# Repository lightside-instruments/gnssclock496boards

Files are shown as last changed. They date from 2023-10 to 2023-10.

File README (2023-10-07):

The gnssclock496boards is an open hardware extension module for Ultra96
or other 96boards CE compatible devices. It uses the u-blox LEA-M8T
module or other LEA-* compatible modules.

In addition to a 1 sec PPS signal which is available on almost all
GNSS boards it has high frequency (e.g. 10 MHz clock signal) that
can be used for better precision timestamp or frequency synchronization.

Published by Lightside Instruments AS.

The initial release gnssclock496boards-1.0 includes schematic and PCB
design files for KiCAD.

The project is published by Lightside Instruments AS
under TAPR Open Hardware License. Read the LICENSE file
for details.

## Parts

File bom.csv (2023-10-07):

Reference | Quantity | Identifier | footprint | Value | Tolerance | Voltage | Current | Power | PN
BT1 | 1 |  | ice4pi:BatteryHolder_Keystone_2450 | Battery_Cell |  |  |  |  | SMTU2450N-LF.TR
C1;C5 | 2 |  | Resistor_SMD:R_0402_1005Metric | 1uF |  |  |  |  | 885012105012
C2;C7 | 2 |  | Capacitor_SMD:C_0402_1005Metric | 10uF |  |  |  |  | ZRB15XR61A106ME01D
C3 | 1 |  | Capacitor_SMD:C_0402_1005Metric | 1uF |  |  |  |  | 885012105012
C4 | 1 |  | Inductor_SMD:L_0402_1005Metric | 22pF |  |  |  |  | 885012005009
D2;D1 | 2 |  | Resistor_SMD:R_0402_1005Metric | D_TVS |  |  |  |  | PESD0402-140
D3 | 1 |  | Diode_SMD:D_0603_1608Metric | LED |  |  |  |  | 150060VS55040
J1 | 1 |  | ice4pi:Socket_Strip_SMD_2x20_Pitch2mm | Conn_02x20_Odd_Even |  |  |  |  | 55510-140LF
J2;J6;J5 | 3 |  | ice4pi:SMA_LINX_CONSMA002_Horizontal | Conn_01x01_Shielded |  |  |  |  | CONSMA002
J4 | 1 |  | ice4pi:Pin_Header_SMD_2x20_Pitch2mm | Conn_02x20_Odd_Even |  |  |  |  | 87759-4051
L1 | 1 |  | Inductor_SMD:L_0402_1005Metric | 27nH |  |  |  |  | 7447840027G
Q1 | 1 |  | Package_TO_SOT_SMD:SOT-323_SC-70 | Q_NPN_BEC_BRT |  |  |  |  | PDTC114EU,115
R1;R2 | 2 |  | Resistor_SMD:R_0805_1005Metric | 51 |  |  |  |  | ERJ-P06J510V
R3 | 1 |  | Resistor_SMD:R_0402_1005Metric | 10K |  |  |  |  | ERJ-2GEJ103X
R4 | 1 |  | Resistor_SMD:R_1206_3216Metric | 10R |  |  |  |  | CR1206-FX-10R0ELF
R5 | 1 |  | Resistor_SMD:R_0402_1005Metric | 0R |  |  |  |  | ERJ-U020R00X
R6 | 1 |  | Resistor_SMD:R_0402_1608Metric | 1K |  |  |  |  | ERJ-2GEJ102X
R7;R8;R10;R11 | 4 |  | Resistor_SMD:R_0402_1005Metric | 4K7 |  |  |  |  | CR0402-JW-472GLF
R9 | 1 |  | Resistor_SMD:R_0402_1005Metric | 200K |  |  |  |  | MCS04020C2003FE000
U1;U2 | 2 |  | Package_SO:TSOP-5_1.65x3.05mm_P0.95mm | 74LVC1G125 |  |  |  |  | 74LVC1G125GV,125
U10 | 1 |  | Package_SO:SO-8_3.9x4.9mm_P1.27mm | PCA9306 |  |  |  |  | PCA9306D,118
U3;U8;U4;U7;U9 | 5 |  | Package_TO_SOT_SMD:SOT-23-5 | SN74LV1T34DBVRG4 |  |  |  |  | SN74LV1T34DBVRG4
U5 | 1 |  | Package_TO_SOT_SMD:SOT-223-3_TabPin2 | LD1117S33TR_SOT223 |  |  |  |  | LD1117S33TR
U6 | 1 |  | RF_GPS:ublox_LEA | LEA-M8T |  |  |  |  | LEA-M8T-0

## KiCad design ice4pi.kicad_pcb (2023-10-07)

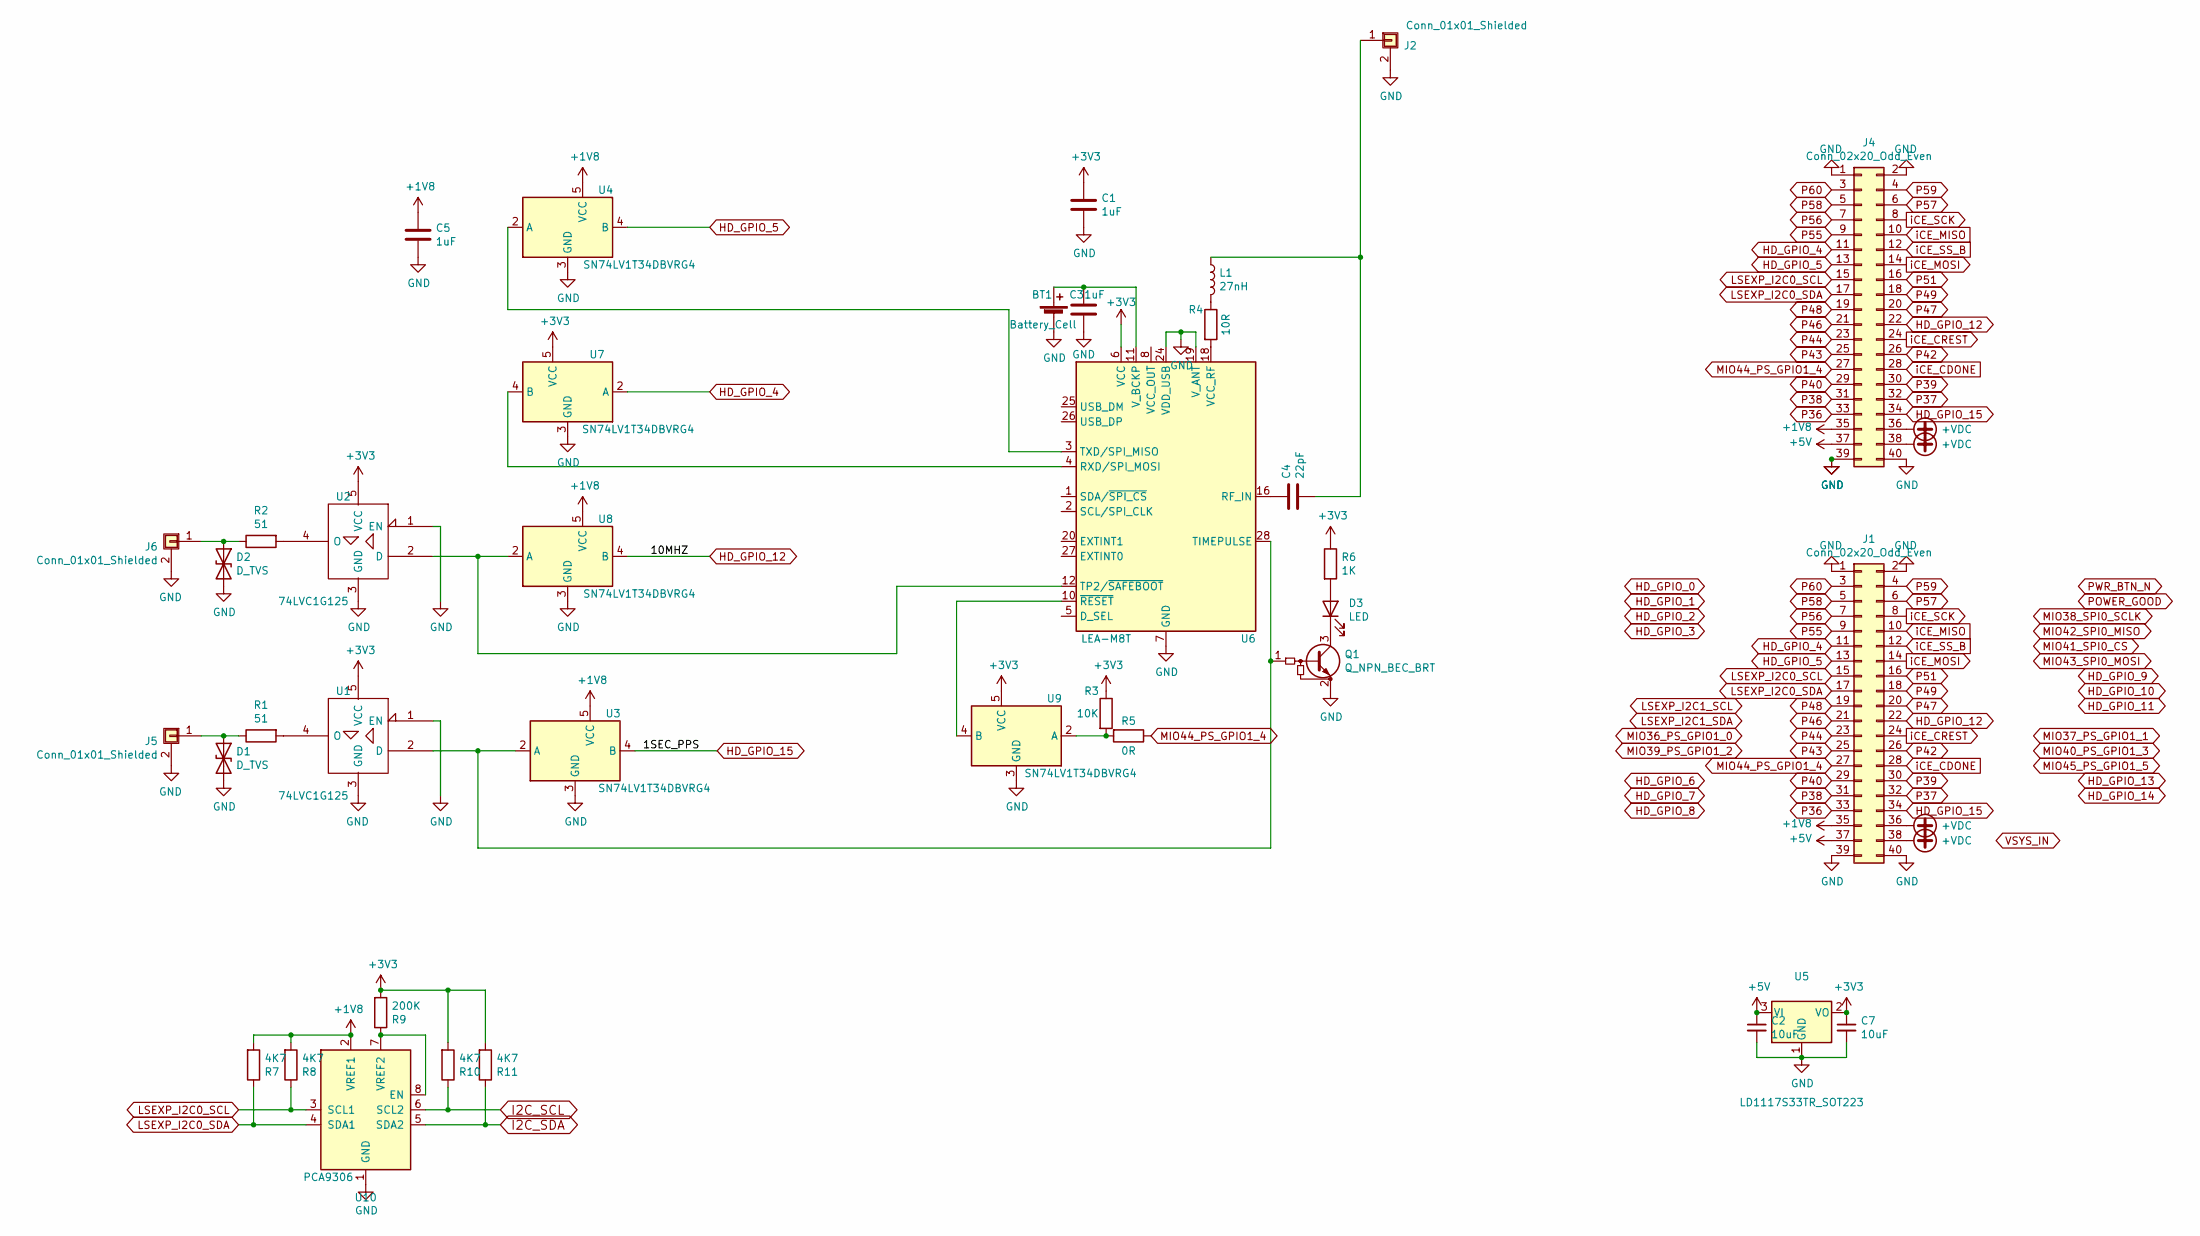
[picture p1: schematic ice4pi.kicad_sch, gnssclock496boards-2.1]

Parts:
BT1: Battery_Cell; BatteryHolder_Keystone_2450
C1, C5: 1uF; R_0402_1005Metric
C2, C7: 10uF; C_0402_1005Metric
C3: 1uF; C_0402_1005Metric
C4: 22pF; L_0402_1005Metric
D1, D2: D_TVS; R_0402_1005Metric
D3: LED; D_0603_1608Metric
J1: Conn_02x20_Odd_Even; Socket_Strip_SMD_2x20_Pitch2mm
J2, J5, J6: Conn_01x01_Shielded; SMA_LINX_CONSMA002_Horizontal
J4: Conn_02x20_Odd_Even; Pin_Header_SMD_2x20_Pitch2mm
L1: 27nH; L_0402_1005Metric
Q1: Q_NPN_BEC_BRT; SOT-323_SC-70
R1, R2: 51; R_0805_2012Metric
R3: 10K; R_0402_1005Metric
R4: 10R; R_1206_3216Metric
R5: 0R; R_0402_1005Metric
R6: 1K; R_0402_1005Metric
R7, R8, R10, R11: 4K7; R_0402_1005Metric
R9: 200K; R_0402_1005Metric
U1, U2: 74LVC1G125; TSOP-5_1.65x3.05mm_P0.95mm
U3, U4, U7, U8, U9: SN74LV1T34DBVRG4; SOT-23-5
U5: LD1117S33TR_SOT223; SOT-223-3_TabPin2
U6: LEA-M8T; ublox_LEA
U10: PCA9306; SO-8_3.9x4.9mm_P1.27mm

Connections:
+1V8: C5.1, J1.35, J4.35, R7.2, R8.2, U3.5 (VCC), U4.5 (VCC), U8.5 (VCC), U10.2 (VREF1)
+3V3: C1.1, C7.1, R3.1, R6.1, R9.2, R10.2, R11.2, U1.5 (VCC), U2.5 (VCC), U5.2 (VO), U6.6 (VCC), U7.5 (VCC), U9.5 (VCC)
+5V: C2.1, J1.37, J4.37, U5.3 (VI)
+VDC: J1.36, J1.38, J4.36, J4.38
GND: BT1.2 (-), C1.2, C2.2, C3.2, C5.2, C7.2, D1.2 (A2), D2.2 (A2), J1.1, J1.2, J1.39, J1.40, J2.2 (Shield), J4.1, J4.2, J4.39, J4.40, J5.2 (Shield), J6.2 (Shield), Q1.2 (E), U1.1 (EN), U1.3 (GND), U2.1 (EN), U2.3 (GND), U3.3 (GND), U4.3 (GND), U5.1 (GND), U6.7 (GND), U6.13 (GND), U6.14 (GND), U6.15 (GND), U6.17 (GND), U6.19 (V_ANT), U6.24 (VDD_USB), U7.3 (GND), U8.3 (GND), U9.3 (GND), U10.1 (GND)
HD_GPIO_4: J1.11, J4.11, U7.2 (A)
HD_GPIO_5: J1.13, J4.13, U4.4 (B)
HD_GPIO_12: J1.22, J4.22, U8.4 (B)
HD_GPIO_15: J1.34, J4.34, U3.4 (B)
I2C_SCL: R10.1, U10.6 (SCL2)
I2C_SDA: R11.1, U10.5 (SDA2)
LSEXP_I2C0_SCL: J1.15, J4.15, R8.1, U10.3 (SCL1)
LSEXP_I2C0_SDA: J1.17, J4.17, R7.1, U10.4 (SDA1)
MIO44_PS_GPIO1_4: J1.27, J4.27, R5.1
unnamed: BT1.1 (+), C3.1, U6.11 (V_BCKP)
unnamed: C4.1, U6.16 (RF_IN)
unnamed: C4.2, J2.1, L1.1
unnamed: D1.1 (A1), J5.1, R1.1
unnamed: D2.1 (A1), J6.1, R2.1
unnamed: D3.1 (K), Q1.3 (C)
unnamed: D3.2 (A), R6.2
unnamed: L1.2, R4.1
unnamed: Q1.1 (B), U1.2 (D), U3.2 (A), U6.28 (TIMEPULSE)
unnamed: R1.2, U1.4 (O)
unnamed: R2.2, U2.4 (O)
unnamed: R3.2, R5.2, U9.2 (A)
unnamed: R4.2, U6.18 (VCC_RF)
unnamed: R9.1, U10.7 (VREF2), U10.8 (EN)
unnamed: U2.2 (D), U6.12 (TP2/~SAFEBOOT), U8.2 (A)
unnamed: U4.2 (A), U6.3 (TXD/SPI_MISO)
unnamed: U6.4 (RXD/SPI_MOSI), U7.4 (B)
unnamed: U6.10 (~RESET), U9.4 (B)
P36: J1.33, J4.33
P37: J1.32, J4.32
P38: J1.31, J4.31
P39: J1.30, J4.30
P40: J1.29, J4.29
P42: J1.26, J4.26
P43: J1.25, J4.25
P44: J1.23, J4.23
P46: J1.21, J4.21
P47: J1.20, J4.20
P48: J1.19, J4.19
P49: J1.18, J4.18
P51: J1.16, J4.16
P55: J1.9, J4.9
P56: J1.7, J4.7
P57: J1.6, J4.6
P58: J1.5, J4.5
P59: J1.4, J4.4
P60: J1.3, J4.3
iCE_CDONE: J1.28, J4.28
iCE_CREST: J1.24, J4.24
iCE_MISO: J1.10, J4.10
iCE_MOSI: J1.14, J4.14
iCE_SCK: J1.8, J4.8
iCE_SS_B: J1.12, J4.12

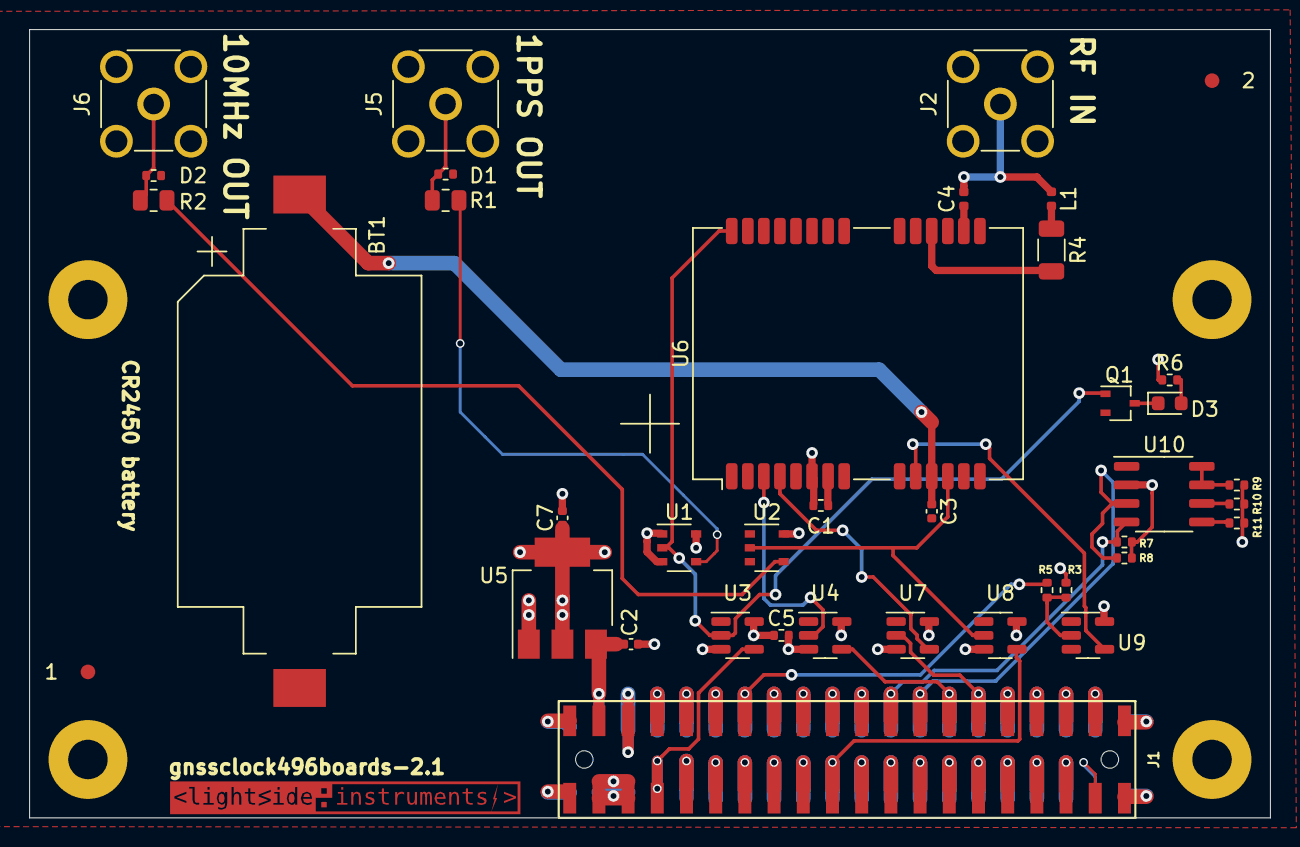
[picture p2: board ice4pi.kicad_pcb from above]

Board: 4 copper layers, 85.0 x 54.0 mm, 45 parts (1 on the bottom side), 57 nets.

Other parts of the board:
1, 2: Fiducial_1mm_Mask3mm
M0, M1, M2, M2#2: MountingHole_2.7mm_Pad
svg2mod: G***; lsi-logo-24mm

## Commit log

2023-10-07 Release gnssclock496boards-1.0
    [bom.csv, ice4pi.kicad_pcb, ice4pi.kicad_sch]
2023-10-07 Release gnssclock496boards-2.0
    [ice4pi.kicad_pcb, ice4pi.kicad_sch]
2023-10-07 Release gnssclock496boards-2.1
    [ice4pi.kicad_pcb, ice4pi.kicad_sch]
